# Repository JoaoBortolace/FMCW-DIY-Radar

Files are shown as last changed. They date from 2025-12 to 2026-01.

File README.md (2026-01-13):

# FMCW-DIY-Radar
Este projeto tem como objetivo projetar para estudo um Radar do tipo Frequency-modulated continuous-wave radar (FM-CW).

# Topologia
Este tipo de radar se baseada na transimssão continua de uma chirp de frequência. Um sinal modulado em uma rampa linear de frequência é transmitido. Sua reflexão é capturada, a distância é estimada através da diferência entre o sinal recebido e o que está sendo transmitido no instante.

395890914-43e02710-3b98-4efa-8052-6310c8257413

# Especificações
Para este radar FMCW o objetivo é projetar um radar operando na faixa SHF na Banda C, especificamente na banda ISM, de 5,725GHz para 5,875GHz. O radar será um mono estático com antenas para transmissão e recepção separadas, para haver alto isolamento.

**Especificações objetivos:**

- Medir distancia e velocidade
- $d_{max}\gt100m$ para alvos com $\sigma=1$  (aproximadamente de um humano adulto)
- $v_{max}\ge15m/s$
- microcontrolador ARM capaz de realizar todo processamento necessário.
- Display LCD para exibição dos resultados.
- PCB de 2/4 camadas feita pela JLCPCB de máximo 100mmx100mm para os circuitos de RF
- PCB de 4 camadas feita pela JLCPCB de máximo 100mmx100mm para os circuitos digitais
- Alimentado pelo USB-C.
- Transferência dos dados brutos para o computador.
- Visualização por interface gráfica em MATLAB ou programa escrito em Julia/Python

# Projeto

# Placa Digital
https://365.altium.com/files/D23D9574-CF08-4959-81D4-2C4755ACD176

A placa digital contém os circuitos digitais e de banda base do radar. O microcontrolador, conversores A/D e D/A, filtros, conexão e alimentação.

Radar-1

A PCB de 85mm x 65mm possuí 4 camadas de cobre com a seguinte configuração: SIG/PWR - GND - GND - SIG/PWR:




# Referências
https://en.wikipedia.org/wiki/Continuous-wave_radar

https://hforsten.com/third-version-of-homemade-6-ghz-fmcw-radar.html

https://www.youtube.com/@MarshallBrunerRF

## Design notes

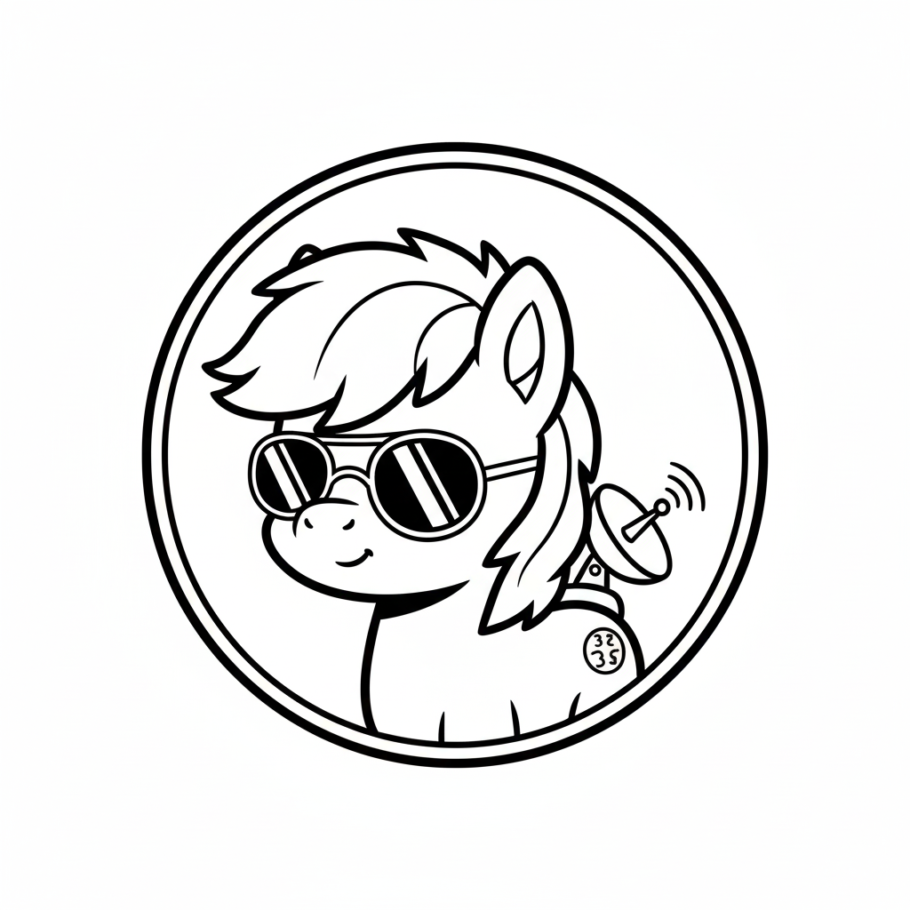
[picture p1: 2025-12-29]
Radar - Placa Digital/Radar_doodle.png

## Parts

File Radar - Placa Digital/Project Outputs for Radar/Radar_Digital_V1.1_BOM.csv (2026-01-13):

Designator | Name | Description | Footprint | Quantity | Manufacturer | Manufacturer Part Number | LCSC Part Number #
C1, C2, C15, C30 | 1u | 1uF �10% 25V Ceramic Capacitor X7R 0603 | CAP_0603 | 4 | Samsung Electro-Mechanics | CL10B105KA8NNNC | C29936
C3, C13 | 4u7 | 4.7uF �10% 25V Ceramic Capacitor X5R 0603 | CAP_0603 | 2 | Samsung Electro-Mechanics | CL10A475KA8NQNC | C69335
C4, C5, C11 | 10u | 10uF �10% 16V Ceramic Capacitor X7R 0805 | CAP_0805 | 3 | Samsung Electro-Mechanics | CL21B106KOQNNNE | C95841
C6, C7, C8, C9, C10, C12, C14, C18, C19, C20, C21, C24, C25, C26, C27, C28, C33 | 100n | 100nF �10% 50V Ceramic Capacitor X7R 0603 | CAP_0603 | 17 | Samsung Electro-Mechanics | CL10B104KB8NNNC | C1591
C16, C17 | 8p | 8pF 50V Ceramic Capacitor NP0 0603 | CAP_0603 | 2 | YAGEO | CC0603CRNPO9BN8R0 | C327316
C22, C23, C29, C32 | 390p | 390pF �5% 50V Ceramic Capacitor C0G 0603 | CAP_0603 | 4 | muRata | GRM1885C1H391JA01D | C701309
C31 | 3n3 | 3.3nF �10% 50V Ceramic Capacitor X7R 0603 | CAP_0603 | 1 | Samsung Electro-Mechanics | CL10B332KB8NNNC | C1613
D1 | ON | Red 625nm LED Indication - Discrete 2.3V 0603 | LED_0603_RED | 1 | XINGLIGHT | XL-1608SURC-06 | C965799
D2 | USBLC6-2SC6 | Low-Capacitance ESD Protection USB | SOT-23-6 | 1 | STMicroelectronics | USBLC6-2SC6 | C7519
D3 | 150080M153000 | Water Clear SMD-4P,2x1.2mm LED Indication - Discrete RoHS | 150080M153000 | 1 | XINGLIGHT | XL-2012RGBC | C965848
FB1, FB2 | 120R | 120O@100MHz 1 Line Ferrite Bead 0603 2A 50mO | FB_0603 | 2 | muRata | BLM18PG121SN1D | C14709
J1 | USB | USB-C (USB TYPE-C) Receptacle Connector 16 Position Surface Mount, Right Angle | USB4105-GF-A-060 | 1 | SHOU HAN | TYPE-C 16PIN 2MD(073) | C2765186
R1, R2, R3, R4, R26 | 1K | 100mW 1kO 75V Thick Film Resistor �100ppm/? �1% 0603 Chip Resistor - Surface Mount RoHS | RES_0603 | 5 | YAGEO | RC0603FR-071KL | C22548
R5, R6, R7, R10, R11, R21, R22, R24, R25 | 5K1 | 100mW 5.1kO 75V Thick Film Resistor �100ppm/? �1% 0603 Chip Resistor - Surface Mount RoHS | RES_0603 | 9 | YAGEO | RC0603FR-075K1L | C105580
R8, R12, R13, R14, R15, R17, R18, R19, R23, R28 | 33R | 100mW 33O 75V Thick Film Resistor �100ppm/? �1% 0603 Chip Resistor - Surface Mount RoHS | RES_0603 | 10 | YAGEO | RC0603FR-0733RL | C108661
R9, R16, R20, R27 | 47K | 100mW 47kO 75V Thick Film Resistor �100ppm/? �1% 0603 Chip Resistor - Surface Mount RoHS | RES_0603 | 4 | YAGEO | RC0603FR-0747KL | C105579
SW1, SW2 | BOOT, RST | Tactile Switch SPST 400gf 2.5mm 4.2mm x 3.2mm Surface Mount | PTS815 | 2 | G-Switch | GT-TC048D-H025-L1 | C843674
U1 | SPX3819M5-L-3-3/TR | 500mA +3.3V Low-Noise LDO Voltage Regulator | SOT-23-5 | 1 | MaxLinear | SPX3819M5-L-3-3/TR | C9055
U2 | STM32U575RGT6 | ARM Cortex-M33 32 Bit 160MHz 51 LQFP-64(10x10) Microcontrollers RoHS | LQFP64-10x10mm_STM | 1 | STMicroelectronics | STM32U575RGT6 | C5270980
U3, U4 | OPA2365AIDR | IC OPAMP GP 2 CIRCUIT 8SOIC | FP-D0008A-MFG | 2 | TI | OPA2365AIDR | C130011
U5 | TLV9062IDGKR | IC CMOS 2 CIRCUIT 8VSSOP | FP-DGK0008A-IPC_A | 1 | TI | TLV9062IDGKR | C398356
X1 | 12MHz | Crystal 12MHz �15ppm 8pF 120O SMD3225-4P | XTAL_3225 | 1 | DIODES | FL1200138 | C526612

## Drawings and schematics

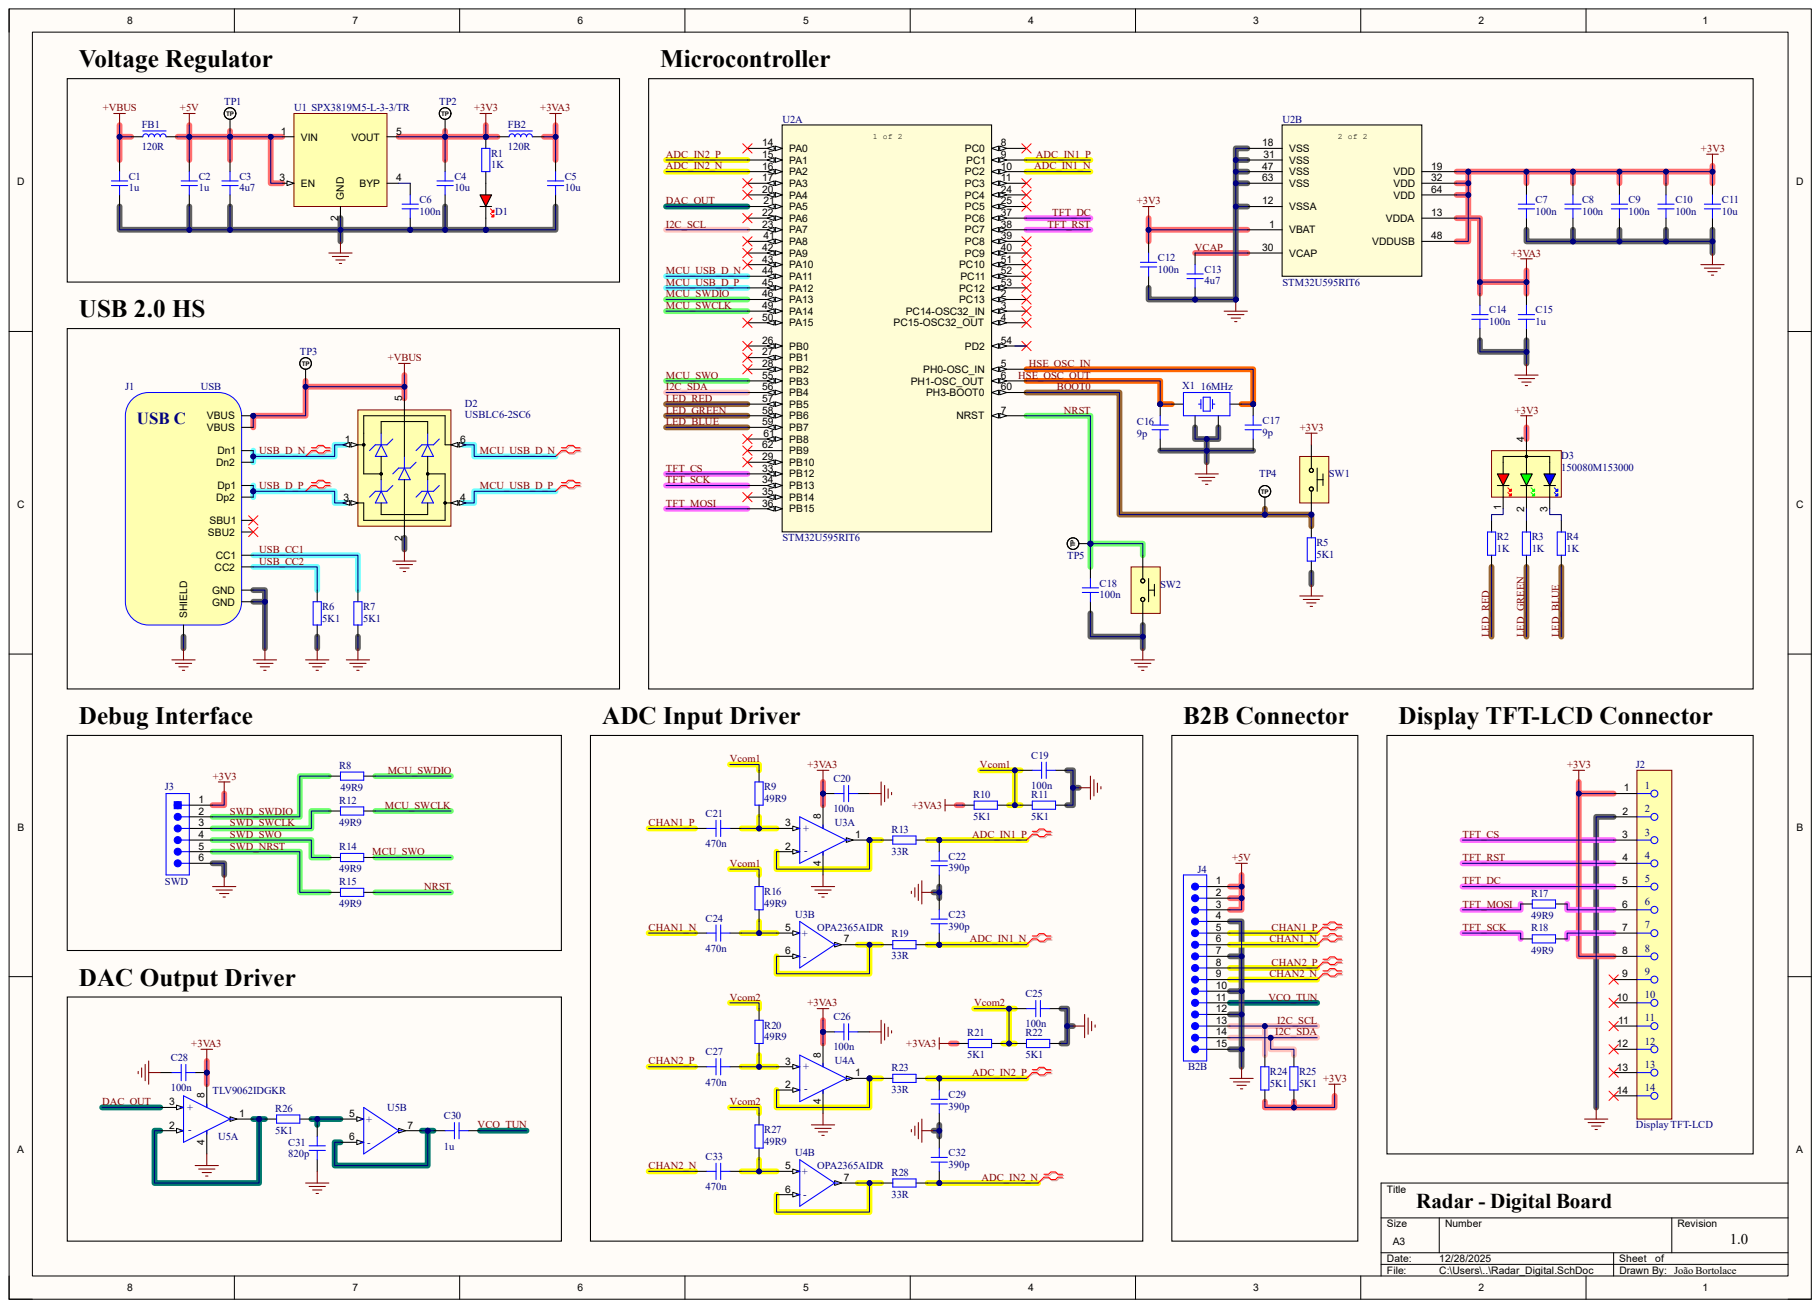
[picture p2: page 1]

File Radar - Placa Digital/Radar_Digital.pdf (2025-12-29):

# Voltage Regulator

# USB 2.0 HS
